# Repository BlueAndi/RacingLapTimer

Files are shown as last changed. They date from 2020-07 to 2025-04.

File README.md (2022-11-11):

# Racing Lap Timer
A racing lap timer, based on a laser sensor.






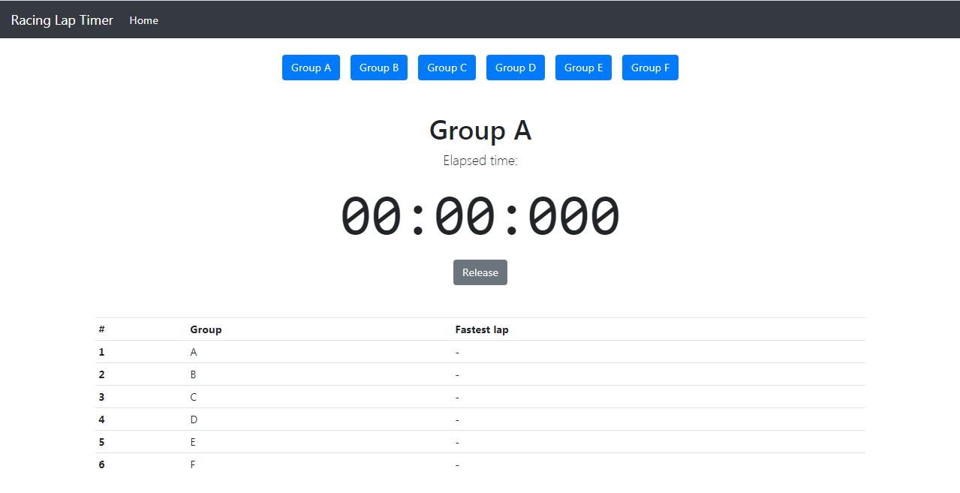
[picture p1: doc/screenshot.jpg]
RacingLapTimer


- [Racing Lap Timer](#racing-lap-timer)
- [Motivation](#motivation)
- [Initial Startup](#initial-startup)
- [Electronic](#electronic)
  - [Schematic](#schematic)
- [Software](#software)
  - [Preparation](#preparation)
  - [IDE](#ide)
  - [Installation](#installation)
  - [Build Project](#build-project)
  - [Update of the device](#update-of-the-device)
    - [Update via usb](#update-via-usb)
  - [Used Libraries](#used-libraries)
  - [System Context](#system-context)
- [Issues, Ideas And Bugs](#issues-ideas-and-bugs)
- [License](#license)
  - [Contribution](#contribution)

# Motivation
For line follower competitions a racing lap timer shall be used. It doesn't only measure the lap time, it shows it nice via web interface, inclusive automatically result table generation.

# Initial Startup
If the system starts up the first time, it will spawn a wifi access point with the SSID RacingLapTimer. Connect to it, it will request a password (default: "let me in").
Configure there the wifi network SSID/password to which the system shall later connect.

After configuration, the system will try to establish a connection. If the connection is not successful, the access point will be spawned again. Otherwise the credentials will be stored to persistent memory and loaded the next time automatically.

# Electronic

* [Wemos D1 Mini (esp8266)](https://docs.platformio.org/en/latest/boards/espressif8266/d1_mini.html)
* [Waveshare laser sensor](https://www.waveshare.com/wiki/Laser_Sensor)

## Schematic

Schematic files can be found [here](./doc/electronic/RacingLapTimer). These have been developed using KiCAD 6.

### MCU
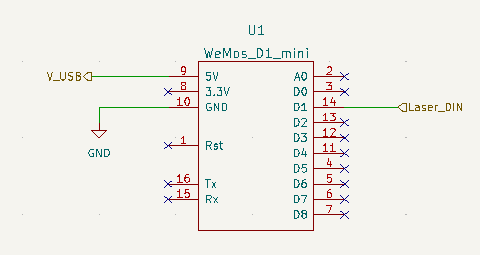
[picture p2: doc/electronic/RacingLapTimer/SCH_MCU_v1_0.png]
MCU

- Digital signal of laser sensor is connected to D1/GPIO_5 of the Wemos D1 Mini.
- Power is supplied by USB 5V directly to the Wemos D1 Mini

### Laser Power Supply
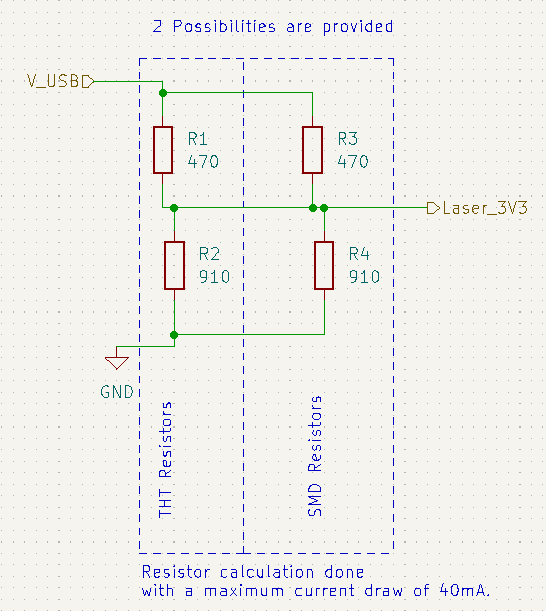
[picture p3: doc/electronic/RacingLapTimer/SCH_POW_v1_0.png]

- Laser module Vcc shall be 3.3V, because MCU is only 3.3V tolerant.
- THT or SMD resistor options are provided. **DO NOT PLACE ALL RESISTORS**.

### Laser Sensor
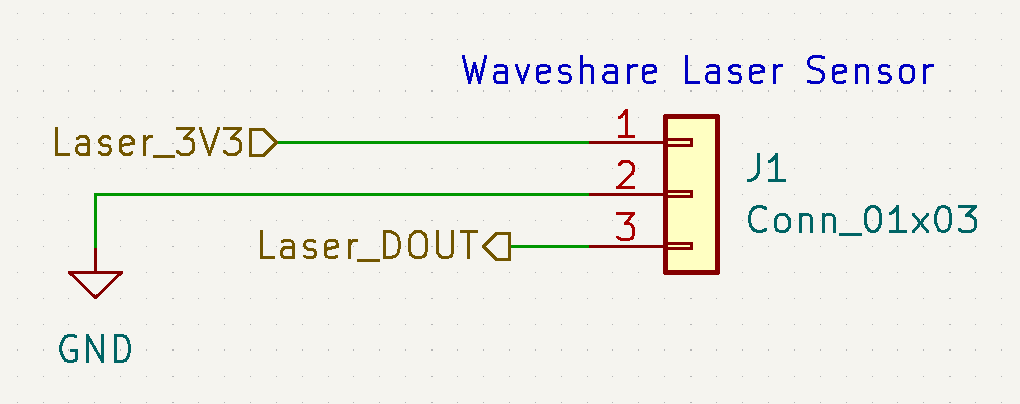
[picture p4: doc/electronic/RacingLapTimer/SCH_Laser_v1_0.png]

- Pin header for Waveshare Laser Sensor.

## PCB 
### v1.0
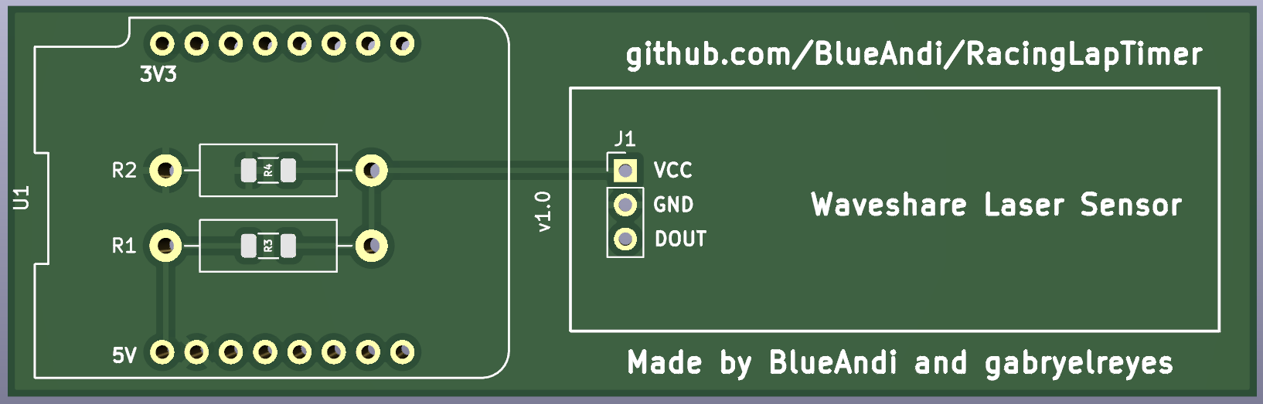
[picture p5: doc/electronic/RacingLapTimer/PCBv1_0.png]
PCBv1.0

- It is recommended to give the Laser Sensor some kind of support in order to protect the pin header from breaking. The height of the support depends on the pin headers used.

# Software

## Preparation
Install the serial driver for the Wemos D1 Mini board. Find the latest drivers here: https://www.wemos.cc/en/latest/ch340_driver.html

## IDE
The [PlatformIO IDE](https://platformio.org/platformio-ide) is used for the development. Its build on top of Microsoft Visual Studio Code.

## Installation
1. Install [VSCode](https://code.visualstudio.com/).
2. Install PlatformIO IDE according to this [HowTo](https://platformio.org/install/ide?install=vscode).
3. Close and start VSCode again.
4. Recommended is to take a look to the [quick-start guide](https://docs.platformio.org/en/latest/ide/vscode.html#quick-start).

## Build Project
1. Load workspace in VSCode.
2. Change to PlatformIO toolbar.
3. _Project Tasks -> Build_ or via hotkey ctrl-alt-b

## Update of the device

### Update via usb
1. Connect the Wemos D1 Mini board to your PC via USB.
2. Build and upload the software via _Project Tasks -> Upload_.
3. Build and upload the filesystem via _Project Tasks -> Upload File System image_.

## Used Libraries
* [Arduino](https://github.com/esp8266/Arduino) - ESP framework.
* [WifiManager](https://github.com/tzapu/WiFiManager) - ESP8266 WiFi Connection manager with fallback web configuration portal.
* [WebSockets](https://github.com/Links2004/arduinoWebSockets) - A WebSocket Server and Client for Arduino based on RFC6455.

## System Context

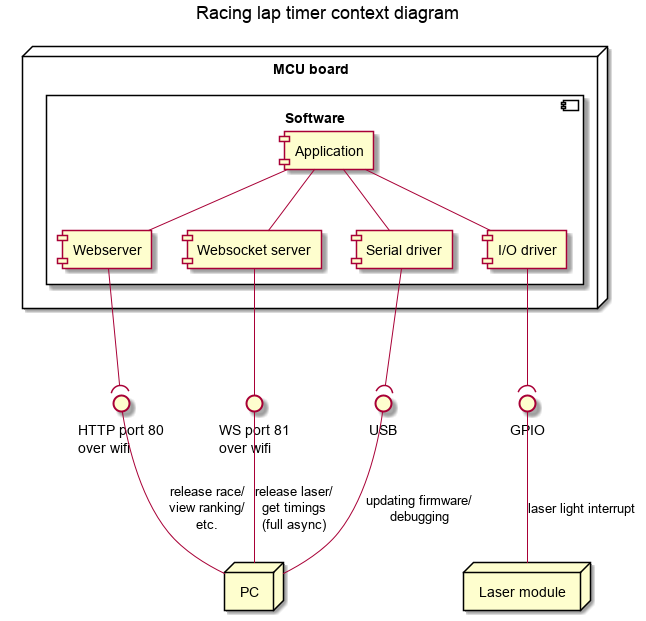
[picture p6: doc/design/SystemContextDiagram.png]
SystemContextDiagram


# Issues, Ideas And Bugs
If you have further ideas or you found some bugs, great! Create a [issue](https://github.com/BlueAndi/RacingLapTimer/issues) or if you are able and willing to fix it by yourself, clone the repository and create a pull request.

# License
The whole source code is published under the [MIT license](http://choosealicense.com/licenses/mit/).

## Contribution
Unless you explicitly state otherwise, any contribution intentionally submitted for inclusion in the work by you, shall be licensed as above, without any
additional terms or conditions.

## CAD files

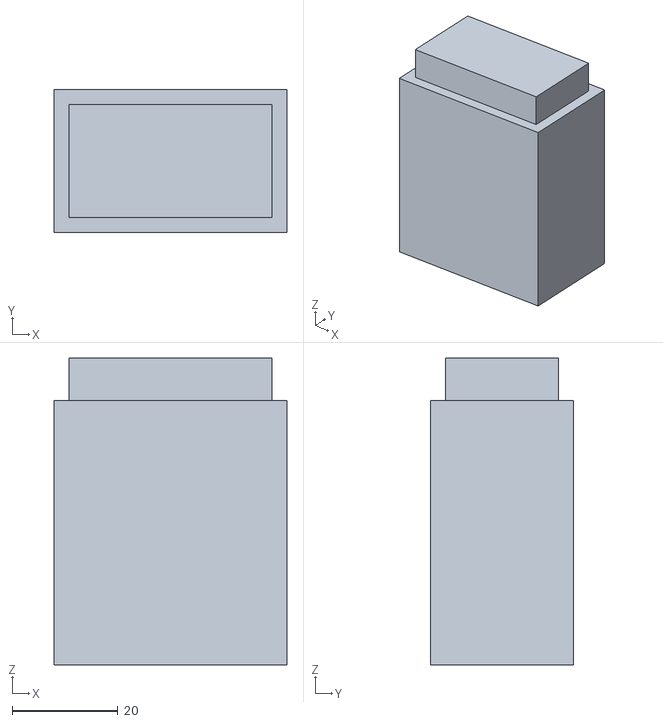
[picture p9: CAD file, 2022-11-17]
doc/mechanic/Right_Leg_Extensor_5cm.stl
44.0 x 27.0 x 58.0

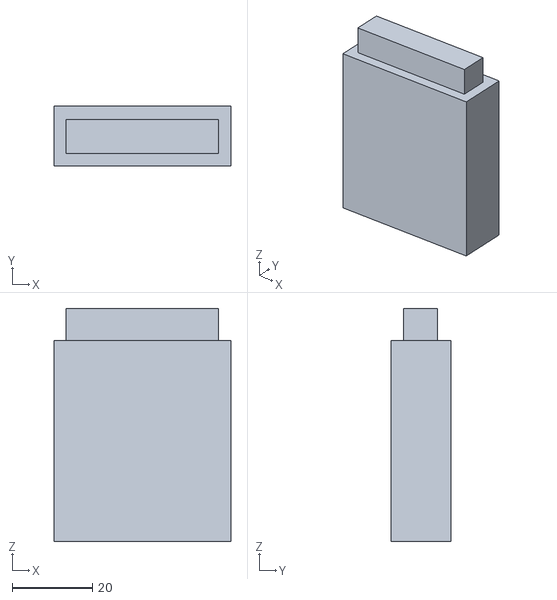
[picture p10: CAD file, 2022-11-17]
doc/mechanic/Left_Leg_Extensor_5cm.stl
44.0 x 15.0 x 58.0

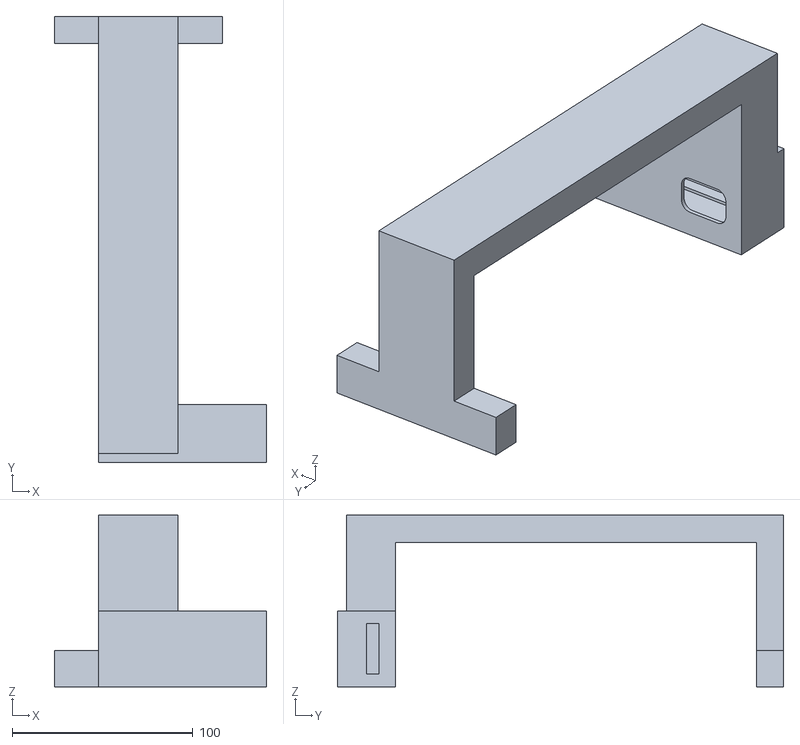
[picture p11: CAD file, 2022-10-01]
doc/mechanic/LaserModulHousingCover_V2.stl
117.5 x 247.0 x 95.0

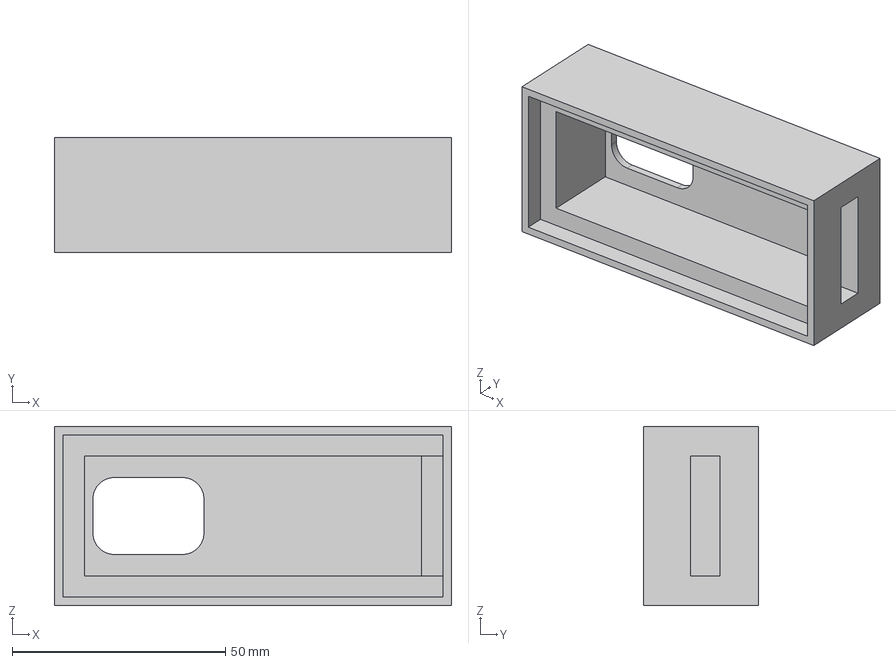
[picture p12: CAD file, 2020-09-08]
doc/mechanic/LaserModulHousingCover.step
93.0 x 27.0 x 42.0 mm

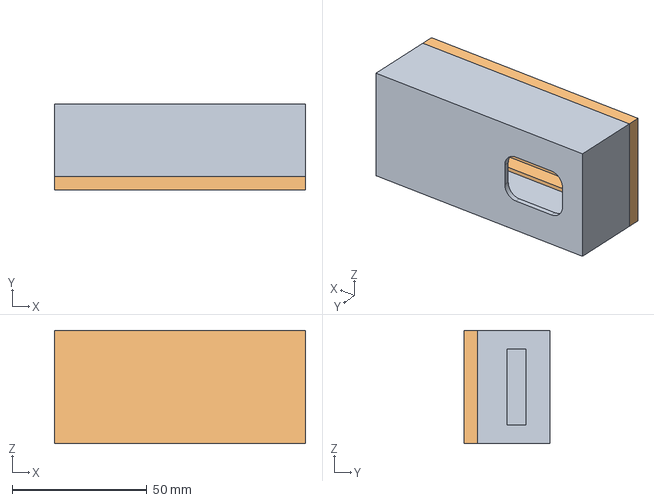
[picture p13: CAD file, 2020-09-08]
doc/mechanic/LaserModulHousingBack.step
93.0 x 32.0 x 42.0 mm

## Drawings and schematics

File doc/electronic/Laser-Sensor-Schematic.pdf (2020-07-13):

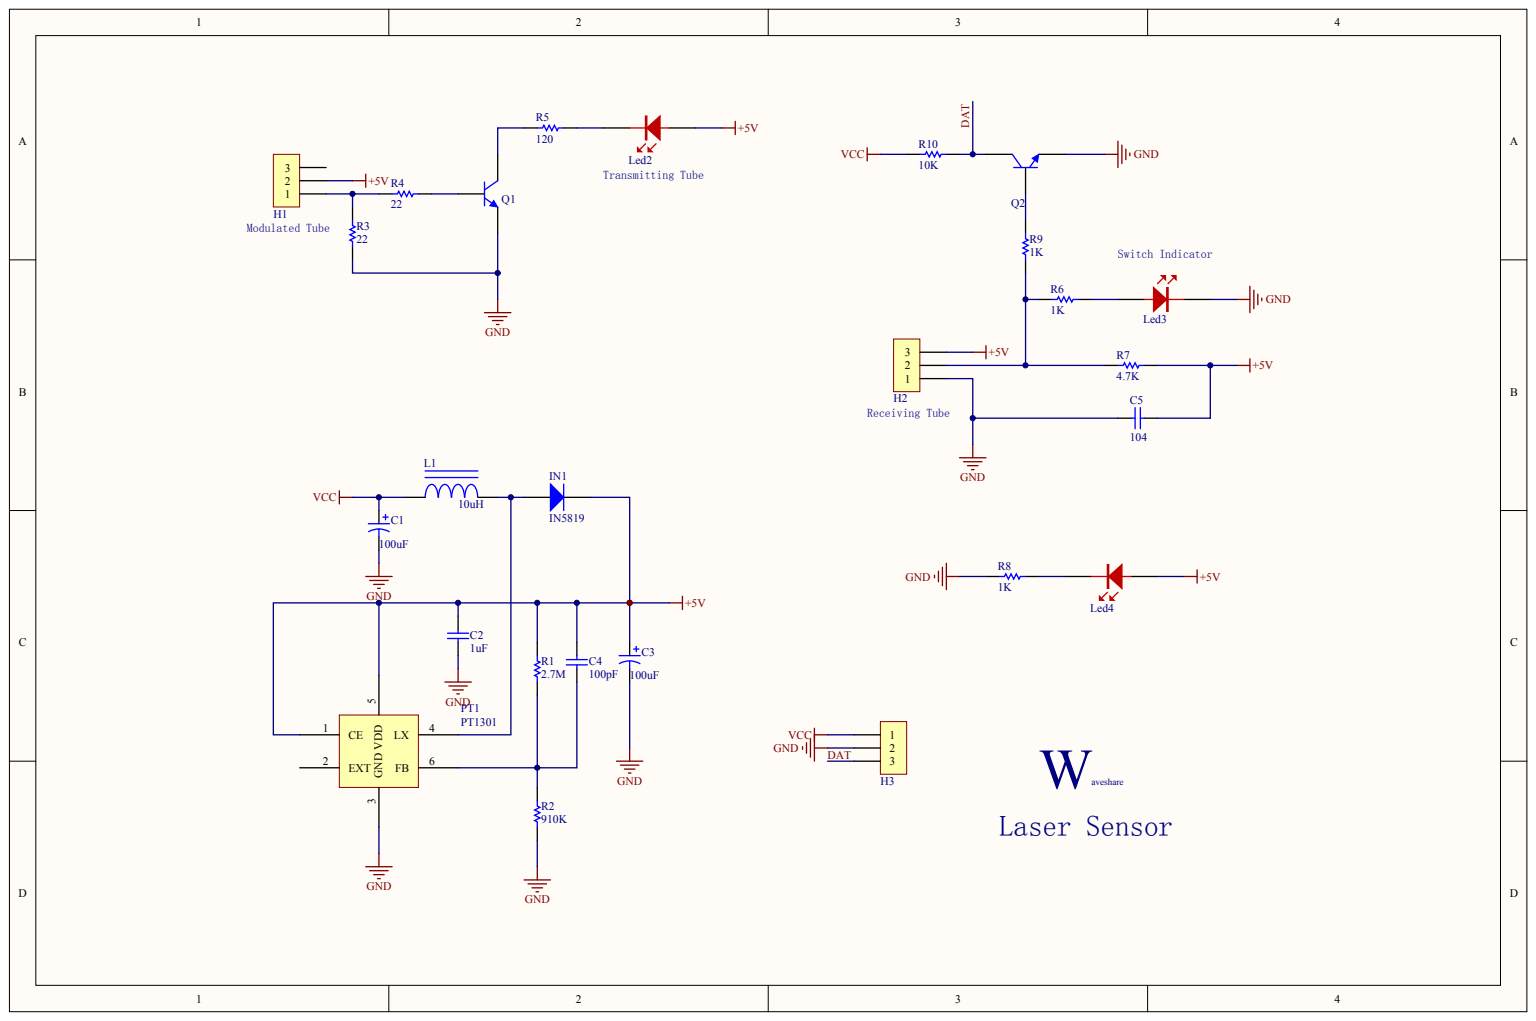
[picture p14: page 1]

C2
1uF PT1 PT1301

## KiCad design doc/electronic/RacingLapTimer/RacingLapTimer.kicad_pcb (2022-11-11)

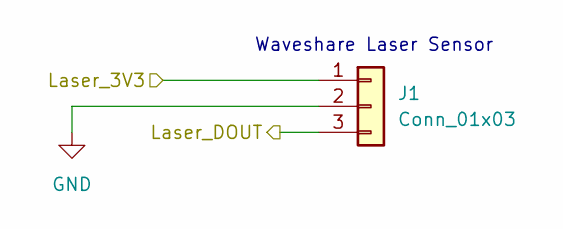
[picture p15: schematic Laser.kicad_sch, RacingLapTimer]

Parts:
J1: Conn_01x03; PinHeader_1x03_P2.54mm_Vertical

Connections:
/Laser/Laser_3V3: J1.1; also elsewhere on the board
/Laser/Laser_DOUT: J1.3; also elsewhere on the board
GND: J1.2; also elsewhere on the board

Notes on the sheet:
Waveshare Laser Sensor

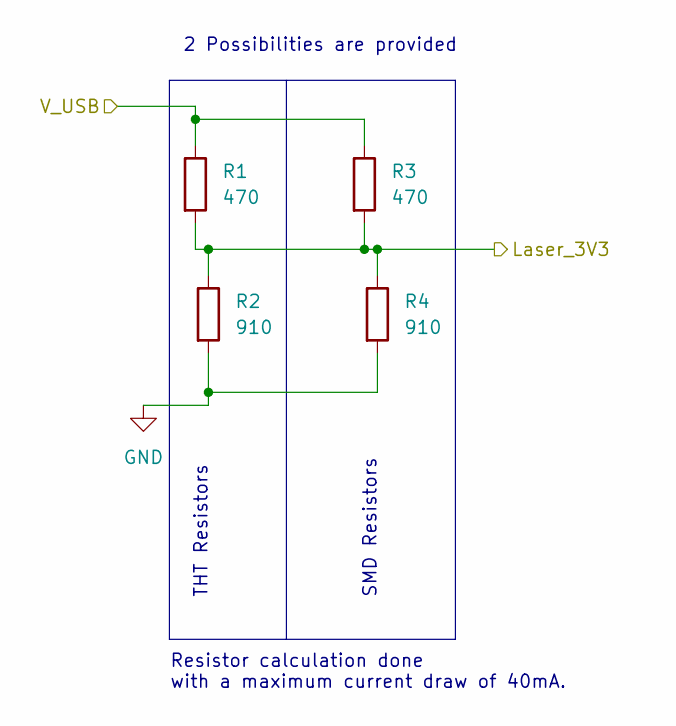
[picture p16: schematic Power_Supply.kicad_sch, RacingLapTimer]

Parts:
R1: 470; R_Axial_DIN0411_L9.9mm_D3.6mm_P15.24mm_Horizontal
R2: 910; R_Axial_DIN0411_L9.9mm_D3.6mm_P15.24mm_Horizontal
R3: 470; R_1206_3216Metric
R4: 910; R_1206_3216Metric

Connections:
/Laser/Laser_3V3: R1.2, R2.1, R3.2, R4.1; also elsewhere on the board
/MCU/V_USB: R1.1, R3.1; also elsewhere on the board
GND: R2.2, R4.2; also elsewhere on the board

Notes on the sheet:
SMD Resistors
2 Possibilities are provided
THT Resistors
Resistor calculation done with a maximum current draw of 40mA.

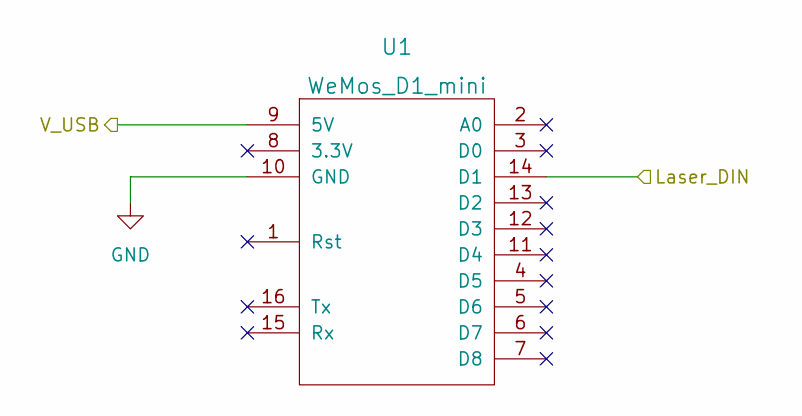
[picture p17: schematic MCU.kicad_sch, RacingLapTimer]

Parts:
U1: WeMos_D1_mini; wemos-d1-mini-with-pin-header-and-connector

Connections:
/Laser/Laser_DOUT: U1.14 (D1); also elsewhere on the board
/MCU/V_USB: U1.9 (5V); also elsewhere on the board
GND: U1.10 (GND); also elsewhere on the board

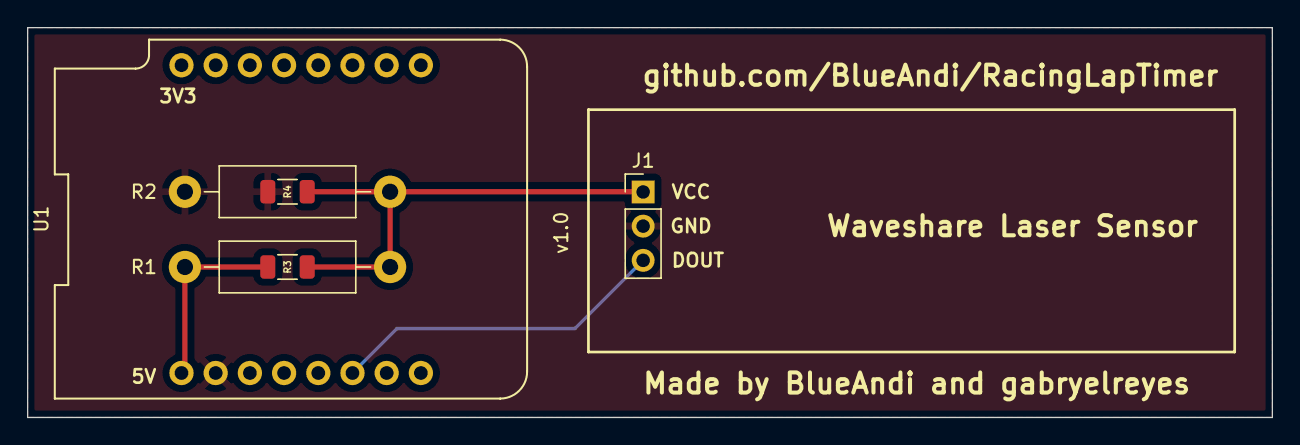
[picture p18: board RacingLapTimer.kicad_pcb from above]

Board: 2 copper layers, 92.5 x 29.0 mm, 6 parts (0 on the bottom side), 4 nets.

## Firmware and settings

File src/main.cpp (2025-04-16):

/* MIT License
 *
 * Copyright (c) 2020 - 2025 Andreas Merkle <web@blue-andi.de>
 *
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
 * THE SOFTWARE IS PROVIDED "AS IS", WITHOUT WARRANTY OF ANY KIND, EXPRESS OR
 * IMPLIED, INCLUDING BUT NOT LIMITED TO THE WARRANTIES OF MERCHANTABILITY,
 * FITNESS FOR A PARTICULAR PURPOSE AND NONINFRINGEMENT. IN NO EVENT SHALL THE
 * AUTHORS OR COPYRIGHT HOLDERS BE LIABLE FOR ANY CLAIM, DAMAGES OR OTHER
 * LIABILITY, WHETHER IN AN ACTION OF CONTRACT, TORT OR OTHERWISE, ARISING FROM,
 * OUT OF OR IN CONNECTION WITH THE SOFTWARE OR THE USE OR OTHER DEALINGS IN THE
 * SOFTWARE.
 */

/*******************************************************************************
    DESCRIPTION
*******************************************************************************/
/**
 * @brief  Main entry point
 * @author Andreas Merkle <web@blue-andi.de>
 */

/******************************************************************************
 * Includes
 *****************************************************************************/

#include "Board.h"
#include "Settings.h"
#include "WIFI.h"
#include "LapTriggerWebServer.h"
#include "Competition.h"
#include "Group.h"

#include <Log.h>

/******************************************************************************
 * Macros
 *****************************************************************************/

/******************************************************************************
 * Types and Classes
 *****************************************************************************/

/******************************************************************************
 * Prototypes
 *****************************************************************************/

/******************************************************************************
 * Variables
 *****************************************************************************/

/** Max. number of participating groups/teams. */
static const size_t         MAX_GROUPS  = 10;

/** The groups/teams, which may take part in the challenge. */
static Group                m_groups[MAX_GROUPS];

/** WiFi Instance */
static WIFI                 gWiFi;

/** Competition Instance */
static Competition          gCompetition(m_groups, MAX_GROUPS);

/** WebServer Instance */
static LapTriggerWebServer  gWebServer(gCompetition);

/******************************************************************************
 * External functions
 *****************************************************************************/

/**
 * Setup the system.
 */
void setup() /* cppcheck-suppress unusedFunction */
{
    bool isError = false;

    /* Initialize HAL. */
    if (false == Board::begin())
    {
        LOG_FATAL("Failed to initialize the HAL.");
        isError = true;
    }
    /* Mount settings. */
    else if (false == Settings::getInstance().begin())
    {
        LOG_FATAL("Failed to mount settings.");
        isError = true;
    }
    /* Start Wireless Connection. */
    else if (false == gWiFi.begin())
    {
        LOG_FATAL("Failed to start wifi.");
        isError = true;
    }
    /* Mount filesystem. */
    else if (false == LittleFS.begin())
    {
        LOG_FATAL("Failed to mount filesystem.");
        isError = false;
    }
    /* Initialize competition */
    else if (false == gCompetition.begin())
    {
        LOG_FATAL("Failed to initialize competition.");
        isError = false;
    }
    /* Start Web Server. */
    else if (false == gWebServer.begin())
    {
        LOG_FATAL("Failed to start webserver.");
        isError = true;
    }
    else
    {
        /* Successful */
        ;
    }

    if (true == isError)
    {
        Board::errorHalt();
    }
    else
    {
        LOG_INFO("Ready.");
    }
}

/**
 * Main loop, which is called periodically.
 */
void loop() /* cppcheck-suppress unusedFunction */
{
    bool isSuccess = true;

    if (false == gWebServer.runCycle())
    {
        isSuccess = false;
    }
    else if (false == gWiFi.runCycle())
    {
        isSuccess = false;
    }
    else
    {
        /* Successful */
        ;
    }

    if (false == isSuccess)
    {
        Board::errorHalt();
    }
}

/******************************************************************************
 * Local functions
 *****************************************************************************/

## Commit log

2020-07-13 Link to laser module fixed.
2020-07-13 WiFi manager requests now a password. Additional the error handling in the setup phase improved.
    [main.cpp]
2020-07-14 TODO regarding electronic schematic added.
2020-09-08 3d housing models added
    [LaserModulHousingBack.step, LaserModulHousingCover.step]
2021-02-22 Implemented Board namespace
2021-02-22 Changed Web Server name to prevent conflicts
    [main.cpp]
2021-02-26 Added missing "static" Keyword for local members
    [main.cpp]
2021-03-03 Fixed Coding Style for WiFi Class
    [main.cpp]
2021-03-03 Fixed Coding Style on main.cpp
    [main.cpp]
2021-03-11 Fixed Bug: Invalid credentials are found after uploading code to Board
2021-03-12 Removed Debugging printf
2021-03-20 Coding style: Module global variables start with a lowercase 'g'. MISRA: A if/else chain shall end with the a "else" to ensure nothing is forgotten.
2021-03-20 Mounting the persistent memory shall be done in the startup initialization, not hidden somewhere in class. If later other classes must be access it too, it would be getting strange.
2021-03-26 #7 Added "Edit Groups" to Settings Page. Added Web socket Connection.
2021-04-30 #9 Added missing brackets
2021-05-28 #10 Created "Clear Laptime" Buttons
2021-11-13 Moved CLEAR ALL button from settings to G.Config
2021-11-13 "Accept Run" button implemented. Functionality not implemented on server
2021-11-13 Implemented accept and reject buttons
2021-11-13 Group names shown in Table and buttons
2022-02-17 Housing V2
    [LaserModulHousingCover_V2.stl]
2022-11-11 Initial Commit of PCB Project. Uses KiCAD 6
    [RacingLapTimer.kicad_pcb, RacingLapTimer.kicad_sch]
2022-11-11 PCB Version 1.0
    [Laser.kicad_sch, MCU.kicad_sch, Power_Supply.kicad_sch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]
2022-11-11 Fixed Missing annotations on silk layer
    [RacingLapTimer.kicad_pcb]
2022-11-11 Added Image of PCB
2022-11-11 Added Pictures of schematic files v1.0
2022-11-17 Leg Extensors added Increase the height of the barrier for use with bigger models
    [Left_Leg_Extensor_5cm.stl, Right_Leg_Extensor_5cm.stl]
2023-09-18 Static check shall fail in case of medium or high priority errors.

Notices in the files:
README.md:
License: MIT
